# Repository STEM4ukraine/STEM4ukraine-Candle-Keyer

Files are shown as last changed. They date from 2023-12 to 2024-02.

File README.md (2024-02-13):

# STEM4ukraine-Candle-Keyer

A simple PCB with an animated candle flicker, iambic Morse keyer, and sound effects set off by pressing of the button!

An ideal school STEM project demonstrating use of GPIO for detecting button presses and paddles with software debouncing, pseudorandom sequences on LEDs to mimic flickering, learning about Morse code, and playing musical tones on the piezo speaker.

Celebrate Ukraine while you key in Morse code, or play the Ukrainian national anthem on the built in speaker!

The front of the PCB

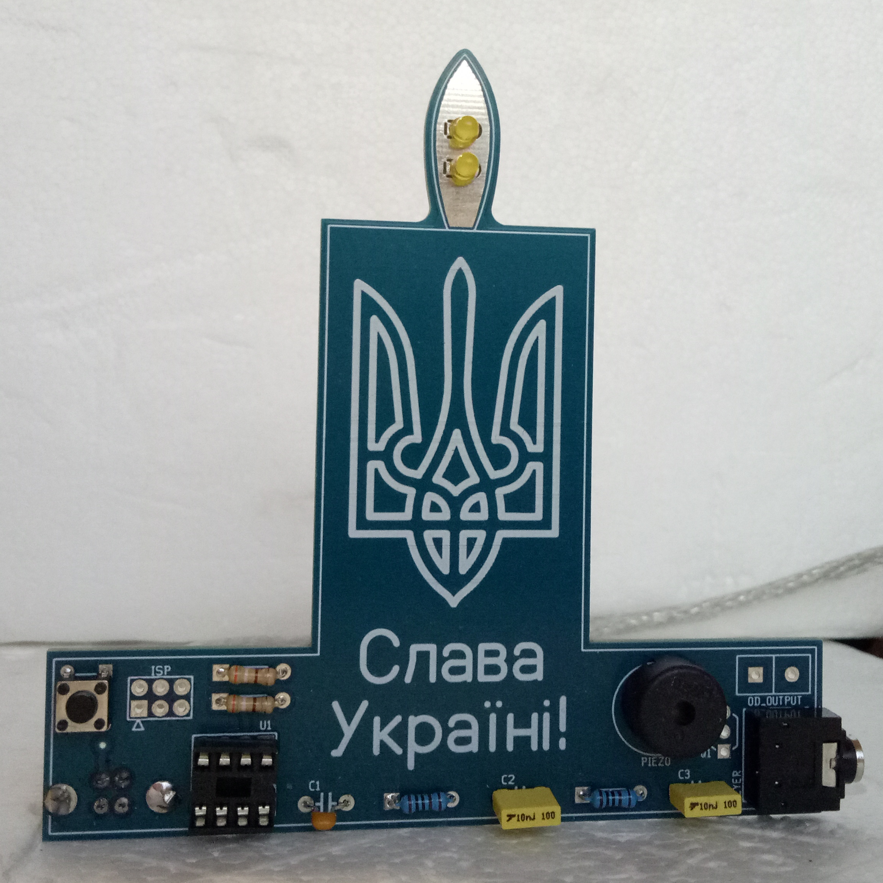
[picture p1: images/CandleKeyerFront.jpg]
prototype front


The schematic:

schematic

Bill of materials:

- U1: attiny13
- C1: 100nF
- C2, C3: 10nF
- R1,R2: 220R
- R3,R4: 1k
- LED1,LED2: yellow 3mm LED
- SW1: momentary switch
- PIEZO: piezo speaker
- KEYER: stereo 3.5mm phono socket for iambic keyer input
- USB1: 180 degree vertical through hole type B USB socket
- Q1: optional, open drain output mosfet, requires RESET pin to be disabled in firmware
- OD_OUTPUT: optional, if Q1 installed, 5.08mm header for external keying line with suitable firmware modifications

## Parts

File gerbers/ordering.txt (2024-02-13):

dimensions 99.5mm high x 100mm wide
blue soldermask
white silkscreen
Pb/Sn pads

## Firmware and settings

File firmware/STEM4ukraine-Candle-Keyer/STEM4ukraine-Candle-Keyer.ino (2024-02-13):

/*
 *
 *   Copyright (C) 2024 STEM4ukraine
 *   Website https://github.com/STEM4ukraine
 *   
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
 */

#include <avr/pgmspace.h>

// this uses https://github.com/MCUdude/MicroCore
// which can be accessed in the boards manager by adding
// https://mcudude.github.io/MicroCore/package_MCUdude_MicroCore_index.json

// the code has been uploaded using an old USB-ASP programmer clone
// and the "USB-ASP slow (Microcore)" setting in the arduino IDE

// Microcore attiny13 selected
// using 1.2MHz internal oscillator
// EEPROM retained
// no bootloader

#define LFSR_INIT1 0xfeed  // non-zero seed value for Galois LFSR used to generate the white noise
#define LFSR_MASK 0x8016   // polynomial from http://users.ece.cmu.edu/~koopman/lfsr/

// note period index is encoded as 4 MSB
// note period index is used to index into a progmem array storing the needed values
// note duration is encoded as 4 LSB
// dit uses the shortest possible note duration
// dah uses the shortest possible note duration times 3

#define DIT_DELAY 112 // 7*16 + 0
#define A_2 107  //6*16 + 11 // 568  // freq 880
#define A_1 103  //6*16 + 7  // 568  // freq 880
#define A_0 99   //6*16 + 3  // 568  // freq 880
#define G1  87   //5*16 + 7  // 638  // freq 784
#define G0  83   //5*16 + 3  // 638  // freq 784
#define FS3 79   //4*16 + 15 // 676  // freq 740
#define FS2 75   //4*16 + 11 // 676  // freq 740
#define FS1 71   //4*16 + 7  // 676  // freq 740
#define FS0 67   //4*16 + 3  // 676  // freq 740
#define FSDAH 66 //4*16 + 2  // 676  // freq 740 DAH F Sharp
#define FSDIT 64 //4*16 + 0  // 676  // freq 740 DIT F Sharp
#define E1  55   //3*16 + 7  // 758  // freq 659
#define E0  51   //3*16 + 3  // 758  // freq 659
#define D1  39   //2*16 + 7  // 851  // freq 587
#define D0  35   //2*16 + 3  // 851  // freq 587
#define CS1 23   //1*16 + 7  // 902  // freq 554
#define CS0 19   //1*16 + 3  // 902  // freq 554
#define B3  15   //0*16 + 15 // 1012 // freq 494
#define B2  11   //0*16 + 11 // 1012 // freq 494
#define B0  3    //0*16 + 3  // 1012 // freq 494

#define NOTE_DELAY_MS 10 // delay between notes

static const uint16_t note_periods[8] PROGMEM = {1012, 902, 851, 758, 676, 638, 568, 500}; // use 500 to denote pause

// we can re-use the music routine to play the dits and dahs as well
static const uint8_t dit_dah[3] PROGMEM = {FSDIT, FSDAH, DIT_DELAY}; // use F sharp for morse sounder of duration 1:3

// first 8 bars
static const uint8_t notes12PD[18] PROGMEM = {FS2, FS0, FS0, E0, FS0, G0, A_2, G0, FS1, E1, D1, FS1, CS1, FS1, B2, CS0, D1, E1};

// 9th-12th bars + 13 into next 3 bars
static const uint8_t notes34PD[18] PROGMEM = {CS1, CS1, FS0, E0, D0, CS0, B0, CS0, D0, B0, CS1, CS1, D1, D1, E1, E1, FS3, FS3};

// final 9 notes of 15-16th bars
static const uint8_t notes4PD[9] PROGMEM = {FS1, CS1, FS1, B2, CS0, D0, E0, FS0, G0};

// next 4 bars + repeat first 11 into next 3 bars
static const uint8_t notes56PD[18] PROGMEM = {A_2, A_0, A_1, FS1, E1, E1, A_0, G0, FS0, E0, D1, D1, E1, E1, FS2, E0, FS1, G1};

// final 5 notes = end of 7th, 8th bar, i.e. index 
static const uint8_t notes6PD[5] PROGMEM = {FS1, CS1, FS1, B3, B3};


uint8_t button = 0, last_key = 0;
uint8_t dit = 0, dah = 0;

void setup() {
  pinMode(0, INPUT_PULLUP); // BUTTON
  pinMode(1, INPUT_PULLUP); // DIT
  pinMode(2, INPUT_PULLUP); // DAH
  pinMode(3, OUTPUT);       // LED1
  pinMode(4, OUTPUT);       // PIEZO
  pinMode(5, INPUT);        // this can be used as an OUTPUT for FET output but only if RESET pin is disabled
}

byte poll_buttons() {
  button = button|!(digitalRead(0));
  dit = dit|!(digitalRead(1));
  dah = dah|!(digitalRead(2));
  return (button | dit | dah);
}

void play_note(const uint8_t * rawnote) {
  int periods, button;
  uint8_t k, raw_note, note_dur;
  uint16_t note_per, cycles, cycles_;

  raw_note = pgm_read_byte(rawnote);
  note_dur = raw_note & 0b00001111;
  periods = ((raw_note>>4) & 0b00001111);
  memcpy_P (&note_per, note_periods+periods, 2);

  // this would need modification for notes outside of the B4-A5 note range
  cycles = (16250)/note_per; // NB avoid overflow for B4-A5 note range. A numerator closer to 65000 would provide more accuracy, but complicate dit/dah timing
  for (k = 0; k < (note_dur + 1); k++) {
    for (int i = 0; i < 3; i++) { // this, times overflow constrained cycles
      cycles_ = cycles;           // gives required duration
      while (cycles_ > 0) {
        if (note_per != 500) { // 500 used to denote delay
          PORTB |= (1 << PB4);
        }
        delayMicroseconds(note_per);
        if (note_per != 500) { // 500 used to denote delay
          PORTB &= ~(1 << PB4);
        }
        delayMicroseconds(note_per);
        cycles_--;
      }
    }
  }
  poll_buttons();
}

void play_dit() {
  play_note(&dit_dah[0]);
  play_note(&dit_dah[2]); // delay
}

void play_dah() {
  play_note(&dit_dah[1]);
  play_note(&dit_dah[2]); // delay
}

void play_anthem() { // breaks if button pressed
  char j, raw_note;
  uint16_t note_dur, note_per;

  // play first 18 notes and then the first 14 again
  for (j = 0; j < 32 && !poll_buttons(); j++) {
    play_note(notes12PD+(j%18));
    delay(NOTE_DELAY_MS);
  }

  // play last note twice
  for (j = 3; j < 5 && !poll_buttons(); j++) {
    play_note(notes6PD+j);
    delay(NOTE_DELAY_MS);
  }

  for (j = 0; j < 31 && !poll_buttons(); j++) {
    play_note(notes34PD+(j%18));
    delay(NOTE_DELAY_MS);
  }

  for (j = 0; j < 9 && !poll_buttons(); j++) {
    play_note(notes4PD+j);
    delay(NOTE_DELAY_MS);
  }

  for (j = 0; j < 29 && !poll_buttons(); j++) {
    play_note(notes56PD+(j%18));
    delay(NOTE_DELAY_MS);
  }

  for (j = 0; j < 5 && !poll_buttons(); j++) {
    play_note(notes6PD+j);
    delay(NOTE_DELAY_MS);
  }

}


// main loop polls the button, and the dit and dah paddles
// lights flicker until a button or paddle has been pressed
void loop() {

  static uint16_t lfsr1 = LFSR_INIT1; 

  while(1) {
    while(!(dit | dah) && !poll_buttons()) { // flicker LEDs while nothing triggered
      if(lfsr1 & 1) {
         lfsr1 =  (lfsr1 >>1) ^ LFSR_MASK;
         PORTB |= (1 << PB3);
      } else {
         lfsr1 >>= 1;
         PORTB &= ~(1 << PB3);
      }
      if(poll_buttons()) break;
      delayMicroseconds(4000);
      if(poll_buttons()) break;
      delayMicroseconds(4000);
      if(poll_buttons()) break;
      delayMicroseconds(4000);
      if(poll_buttons()) break;
      delayMicroseconds(4000);
    }

    if(dit && dah) { // iambic keying
      if(last_key == 1) {
        last_key = 2;
        play_dah();
        dah = 0;
      } else {
        last_key = 1;
        play_dit();
        dit = 0;
      }
    } else if(dit) { // dit keyed
      play_dit();
      last_key = 1;
      dit = 0;
    } else if (dah) { // dah keyed
      play_dah();
      last_key = 2;
      dah = 0;
    } else if (button) { // button pressed
      button = 0;
      last_key = 0;
      delayMicroseconds(80000);
      play_anthem();
      button = 0; // in case button pressed to stop anthem
      delayMicroseconds(80000);
    }

  }
}

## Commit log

2023-12-20 Prototype PCB
2024-02-13 Gerber ordering.txt details
2024-02-13 Add gerber files
    Pinouts fixed to make open collector mosfet output optional, with disabling of RESET pin
    [ukrainian-candle-keyer-v1-1.GBL, ukrainian-candle-keyer-v1-1.GBO, ukrainian-candle-keyer-v1-1.GBS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]
2024-02-13 Add schematic file and pcb layout file
2024-02-13 Add schematic image
2024-02-13 Add BOM and schematic to README.md
2024-02-13 Add ukrainian coat of arms trident footprint

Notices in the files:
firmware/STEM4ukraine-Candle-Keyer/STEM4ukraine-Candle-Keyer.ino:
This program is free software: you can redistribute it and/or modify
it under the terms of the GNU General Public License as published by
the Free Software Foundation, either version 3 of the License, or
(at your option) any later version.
